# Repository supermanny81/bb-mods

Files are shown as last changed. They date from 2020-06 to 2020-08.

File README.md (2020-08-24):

# A collection of BB8 mods

[][cc-by]

Things I've done to my BB8 along the way.

## Chargeport and Power Switch

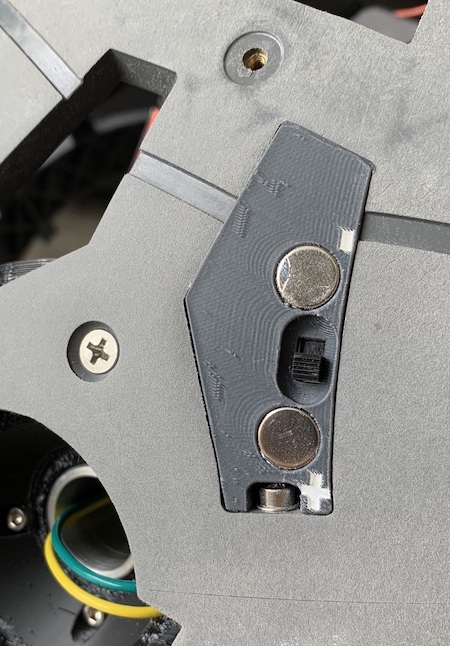
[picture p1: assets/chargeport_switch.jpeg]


The relay I used can be found on Amazon, but I have seen comparable models elsewhere.

https://www.amazon.com/gp/product/B07L6Y7LVW/ref=ppx_yo_dt_b_search_asin_title?ie=UTF8&psc=1

[Charge port power switch](stls/charge_port_micro_switch.stl) - Replaced the wireless relay with a solid state one.

## Dome Lenses

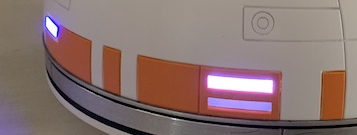
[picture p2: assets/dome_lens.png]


New lenses for addressable LEDs, intended to remove the hot spots.

[Lens for front logics, print 2 of these](stls/dome_front_logics.stl)

[Lens for back logics](stls/dome_back_logics.stl)

## Halo Eletronics Mount

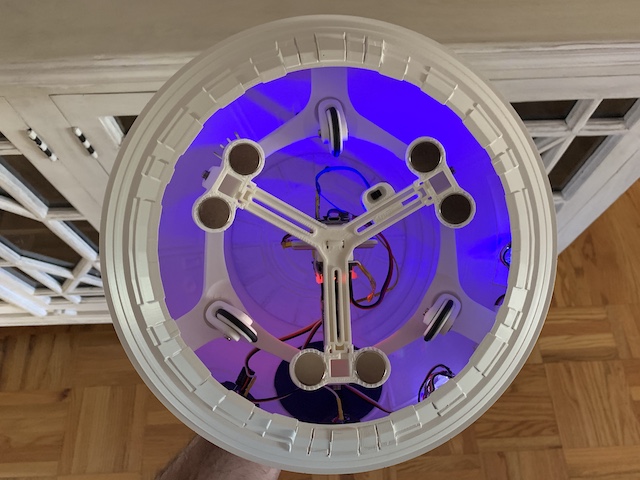
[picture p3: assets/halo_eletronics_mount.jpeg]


Lowers the center of gravity for the battery, provides a mount for the dome's electronics and a switch.  The switch is easily accessible and the dome can be plugged in to charge while on the droid.

[Halo Brace](stls/halo_brace.stl)

[Halo Battery Mount](stls/halo_battery_mount.stl)

[Halo Switch Mount](stls/halo_switch_mount.stl)

## New Lens for Panel 2

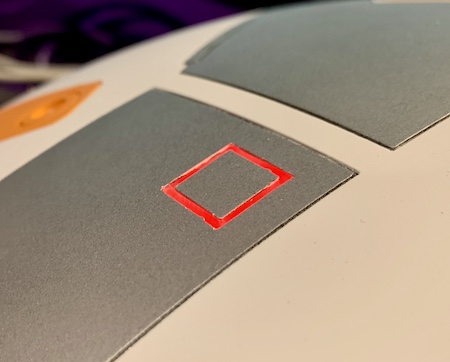
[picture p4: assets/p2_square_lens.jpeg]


[P2 Square Lens STL](stls/p2_square_lens.stl) - A neopixel lens used with Cary's thin panels, this fits in panel 2's square cutout.

## Wireless firmware uploads and control!!!!

One, if not my favorite mods.

[Wireless Firmware Upload and Editing](firmware_upload.md) - With a few simple modifications you can upload new firmware and edit your drive settings no disassembly required.

## WAGO Connector Mount

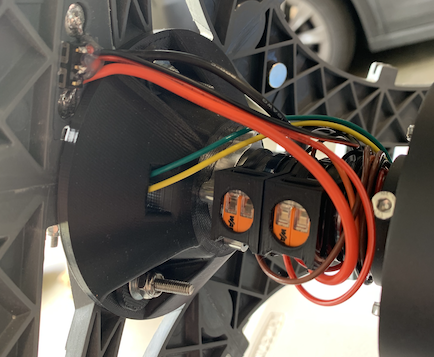
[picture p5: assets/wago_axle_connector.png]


[WAGO Axle Mount STL](stls/wago_axle_mounts.stl) - Easily secure WAGO connectors to your axle using a zip tie.  Can support 4 WAGO connectors per axle.

## Things I've passed up...

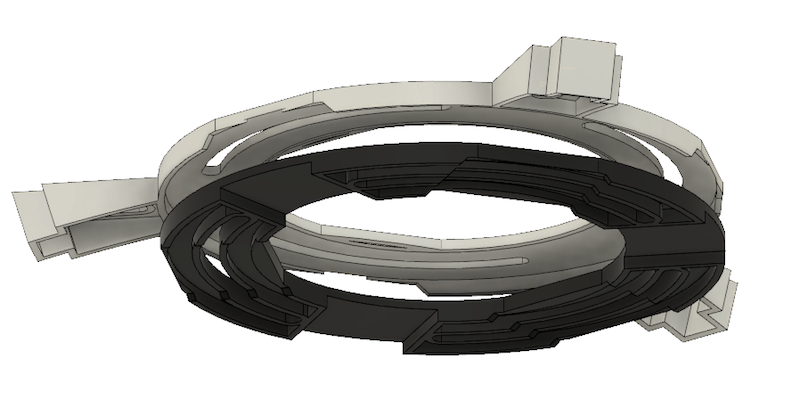
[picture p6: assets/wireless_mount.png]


Mount for induction power coils.  These slide into the Halo setup easily.  I decided to not go this route because of the enefiecient power transfer.  The transmitter coils tolerance for out of spec voltage was bad.  I fried my first.  After regulating it, then looking at the power recived on the other end, it about a 50% power loss.  That coupled with the expensive slip ring and parts, I decided to abandon my effort.  But it's here if you like.

https://www.amazon.com/gp/product/B076H1J7V1/ref=ppx_yo_dt_b_search_asin_title?ie=UTF8&psc=1

[Halo Receiver Mount](stls/halo_receiver_mount.stl) - The receiving mount which attaches the magnet mounts.

[Halo Transmitter Mount](stls/halo_transmitter_mount.stl) - The transmitter mount which attaches the mount inside the body.

[Halo Electronics Mount](stls/halo_electronics_mount.stl) - The board for the dome slides into this mount.

[cc-by]: http://creativecommons.org/licenses/by/4.0/
[cc-by-shield]: https://img.shields.io/badge/License-CC%20BY%204.0-lightgrey.svg

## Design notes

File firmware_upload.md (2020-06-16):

# Wireless flashing and drive editing

There are several settings that are required for wireless firmware flashing to work along with some minor modifications to the hardware.  

The `AT+POLAR` command tells the HC-05 module to use the status LED at it default setting but changes the behavior on the state pin, instead of going high when a serial connection is opened the pin will go low.  Essentially the state pin emulates the DTR pin functionality used with FTDI chips on Arduinos.

Once the software side is configured, you will need a small hardware mod to help emulate the DTR pin/reset switch.

### Software Mods

#### Configuration changes to the modules

Start by changing the settings on your dome's HC-05 module while in `AT Mode`.

```bash
AT+POLAR=1,0
AT+UART=115200,0,0
```

You will need to apply change the baud rate on the HC-05 master used in body to communicate with the dome.

```bash
AT+UART=115200,0,0
```

*I went an extra step further here and made sure that the only address the master module was allowed to bind to was the dome.  You can get the dome HC-05 module's address by running the command `AT+ADDR?` while in `AT` mode.  Then on the master HC-05 run 'AT+BIND=98d3,35,710c09` (but replace 98d3,35,710c09 with your dome's HC-05 module).*

The drive and dome firmware will then need to be updated to use this new baud rate.  The default is current 57600, but the boot loader on new Arduino Nanos expects upgrades at 1152000.

#### Configuring the Drive Console

Now choose a name for console access to your BB unit.  I chose **BB8 Drive Console**.  Remember this name and the pass code you pick, you need to connect this port for changing drive settings and flashing firmware.

**NOTE: Do not use the same passcode that you used for your dome and body HC-05s.**

```
AT+NAME=XXXXXXXX
AT+PSWD=XXXX
AT+ROLE=0
AT+CMODE=1
AT+ROLE=0
AT+POLAR=1,0
AT+UART=115200,0,0
AT+RESET
```

No firmware updates are necessary to enable wireless flashing and drive editing, the drive's Serial0 already runs at the required 115200 bps.

### Hardware Mods

Once configured, make the following circuit.  Technically you can get away with just the 1uf capacitor.  In my case it sometimes failed to reset on when running from arduino's voltage regulator.  Adding the 15k resistor brings the voltage to the reset pin closer to 3v. There is a 10k resistor on the other side of the reset pin, so you are making a voltage divider here . (On my dome, I used an external power supply at 5.2v, without the resistor the voltage never dropped long enough to trigger a reset.)

#### Dome PCB Modifications

Here we are connecting the state pin on the dome's HC-05 module to the reset pin on the dome's PCB with a capacitor in between to *bounce* the voltage drop and trigger a reset on an upload attempt.  Note that the facing the reset pin has a 15k resistor going to ground.

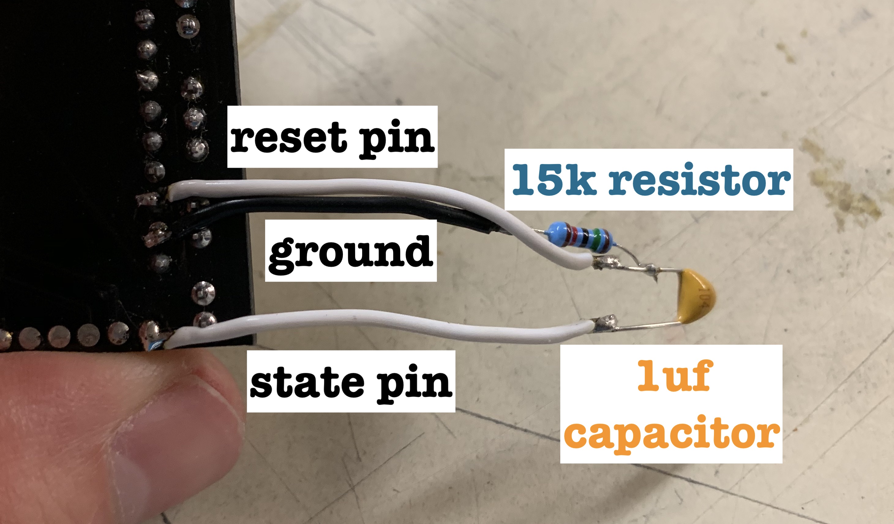
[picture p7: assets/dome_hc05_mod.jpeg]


#### Body (HC-05 Drive Console modifiactions)

I used a ribbon cable created a 5 pin header to connect my drive's HC-05 serial console to the main PCB.  Using a ribbon cable I was able to route my HC-05 module away and secure it to the drive.

Starting from the back side.  Build the same circuit we did for the dome's PCB.  Once again, you will be connecting the HC-05 module's state pin to the reset pin with a 1uf capacitor in between.  Also note again, the resistor goes from a ground pin to leg on the reset side of the capacitor.
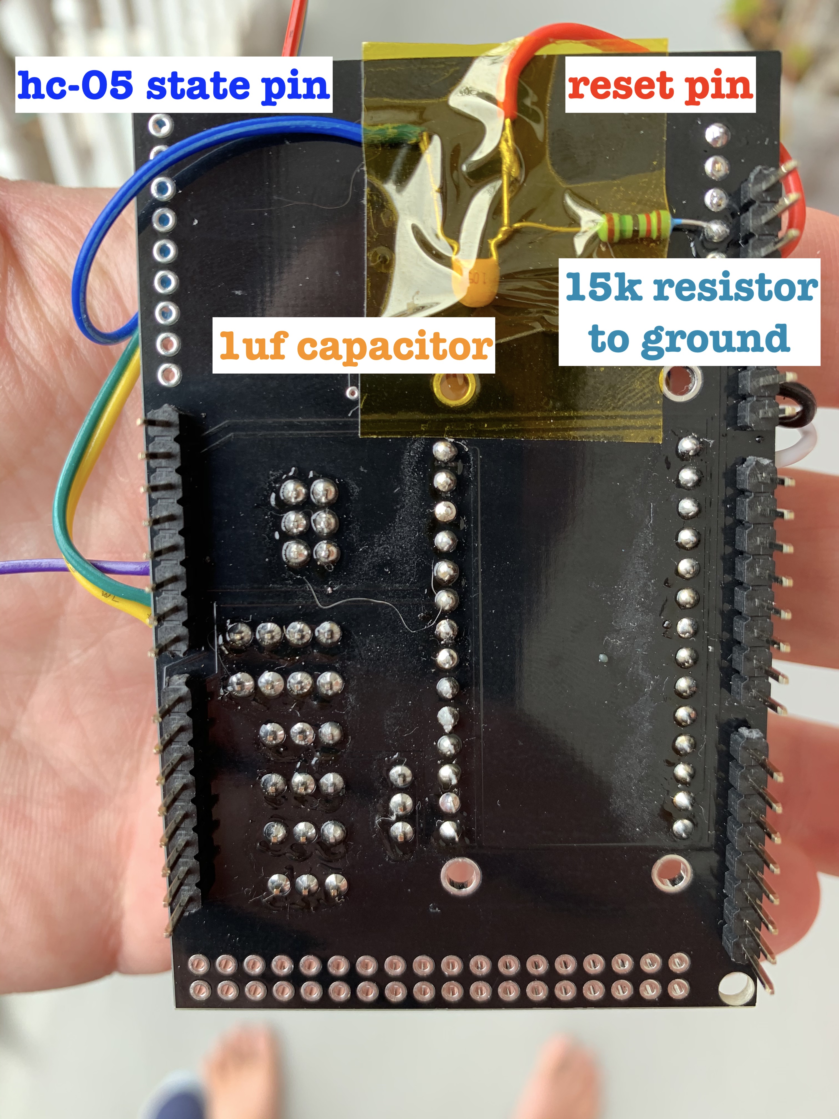
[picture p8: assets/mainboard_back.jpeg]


Once the state pin is connected, flip the board over and make the next 4 connections.  5V, ground, TX, and RX.  You solder them inplace like I did or use a 4 pin header and plug it directly into the board (it's already labled HC-05 along with it's pin outs).  I just got carried away with the soldering iron. :P

*Ignore the voltage divider and body LEDs for now.*

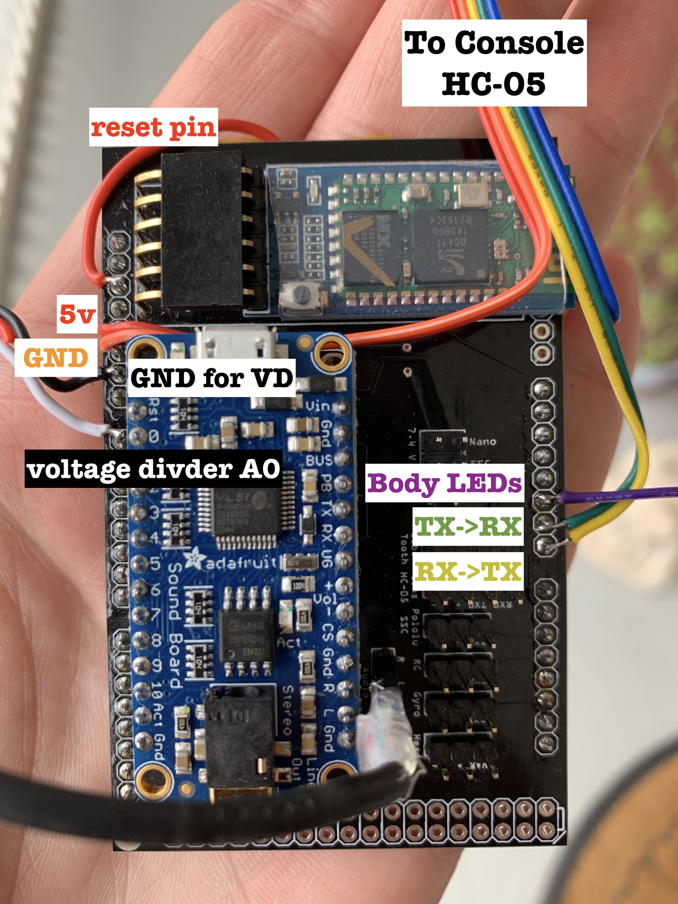
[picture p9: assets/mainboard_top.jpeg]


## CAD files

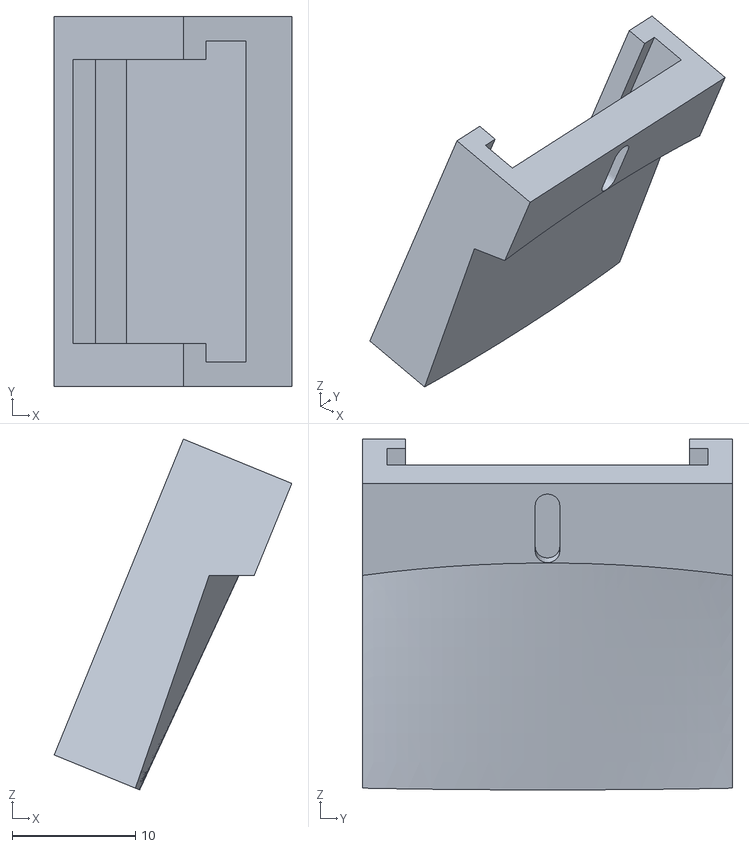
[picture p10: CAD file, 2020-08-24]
stls/halo_electronics_mount.stl
19.3 x 30.0 x 28.4

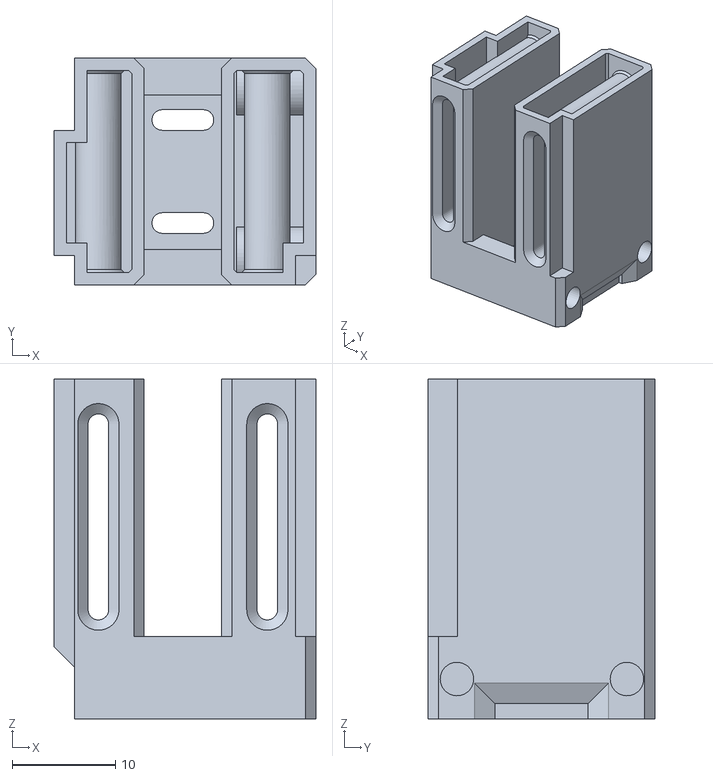
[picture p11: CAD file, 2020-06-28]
stls/halo_battery_mount.stl
25.4 x 22.0 x 33.0

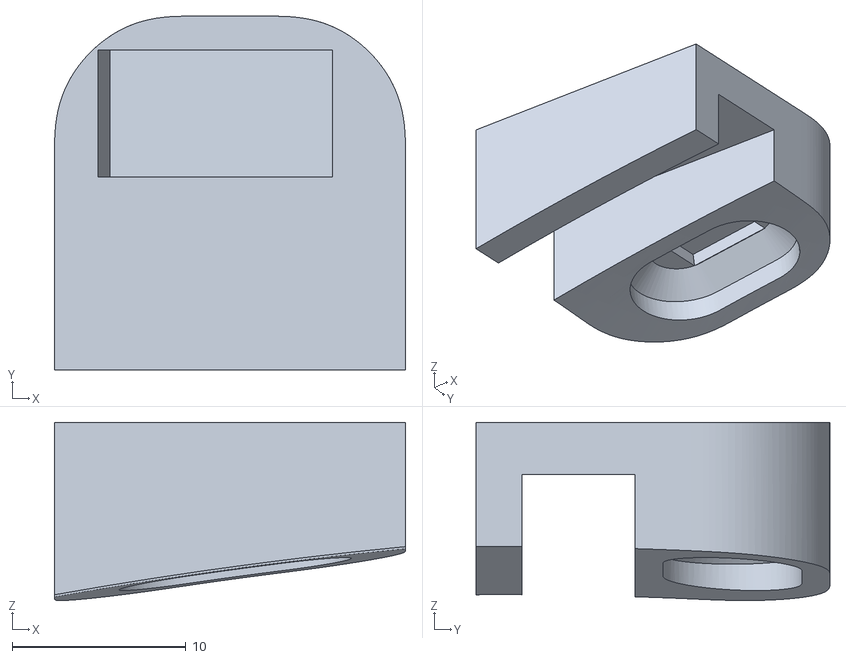
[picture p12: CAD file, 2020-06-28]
stls/halo_switch_mount.stl
20.2 x 20.4 x 10.3

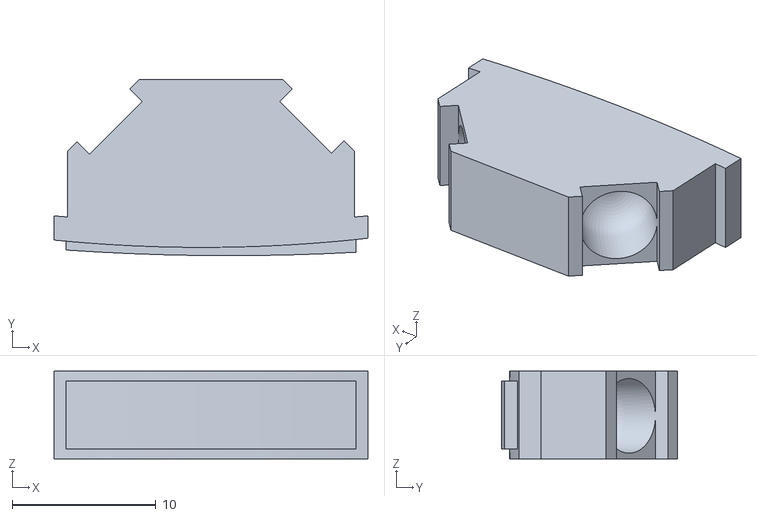
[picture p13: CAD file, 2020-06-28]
stls/dome_back_logics_lens.stl
21.9 x 12.3 x 6.12

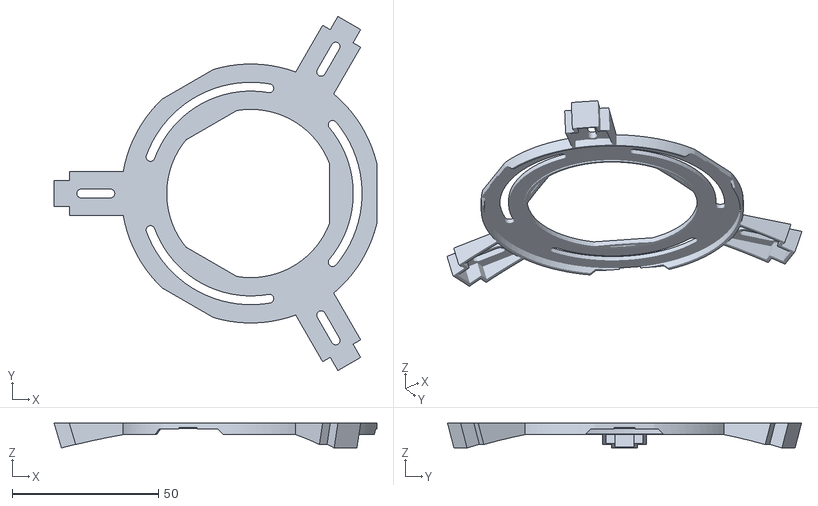
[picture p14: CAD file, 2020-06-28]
stls/halo_receiver_mount.stl
110.4 x 121.0 x 8.50

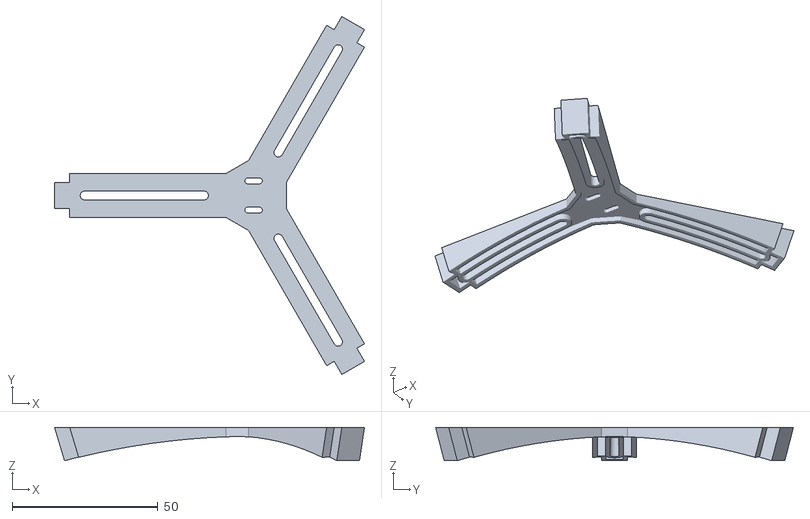
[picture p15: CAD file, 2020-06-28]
stls/halo_brace.stl
106.4 x 122.8 x 11.5

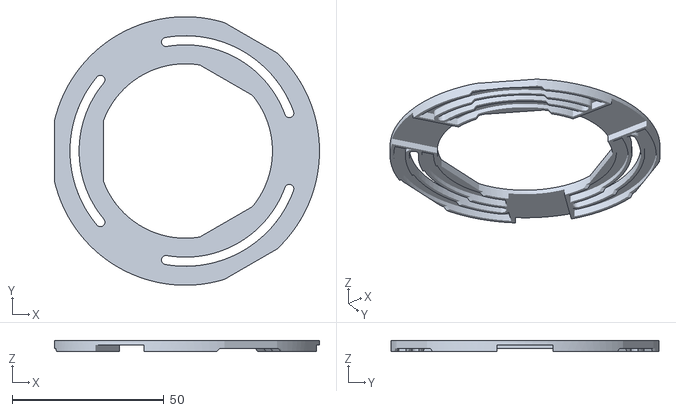
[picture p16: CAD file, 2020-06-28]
stls/halo_transmitter_mount.stl
87.4 x 88.5 x 3.50

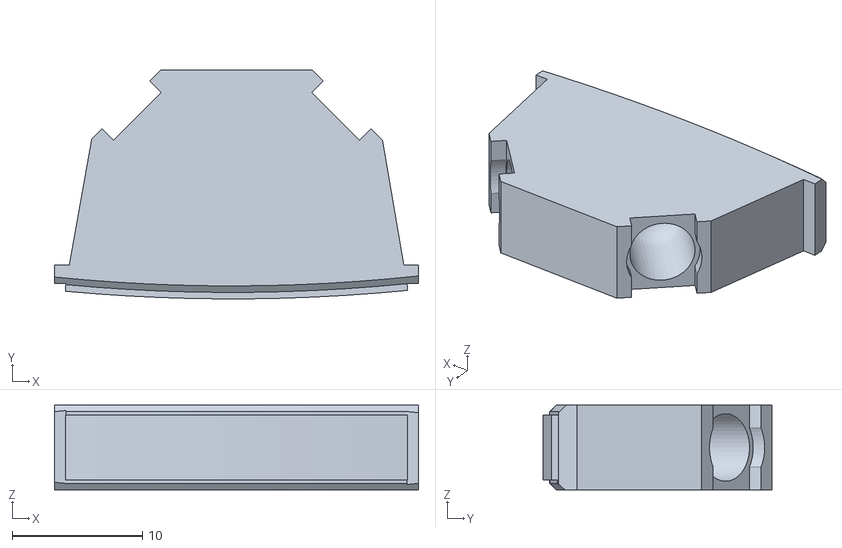
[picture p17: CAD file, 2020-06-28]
stls/dome_front_logics_lens.stl
28.0 x 17.6 x 6.53

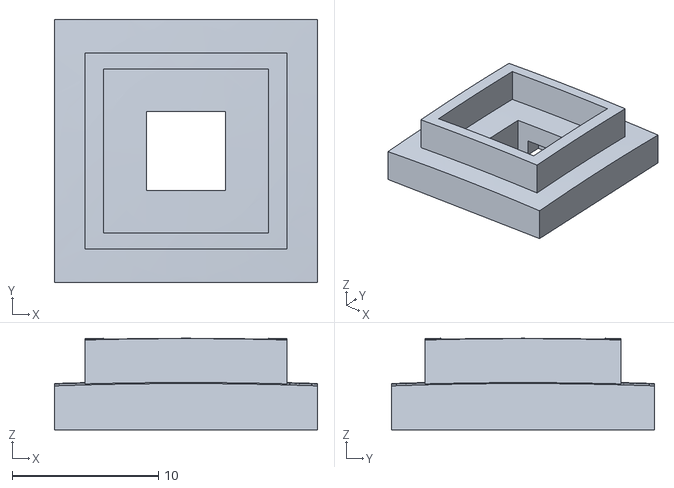
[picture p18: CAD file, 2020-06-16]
stls/p2_square lens.stl
18.0 x 18.0 x 6.27

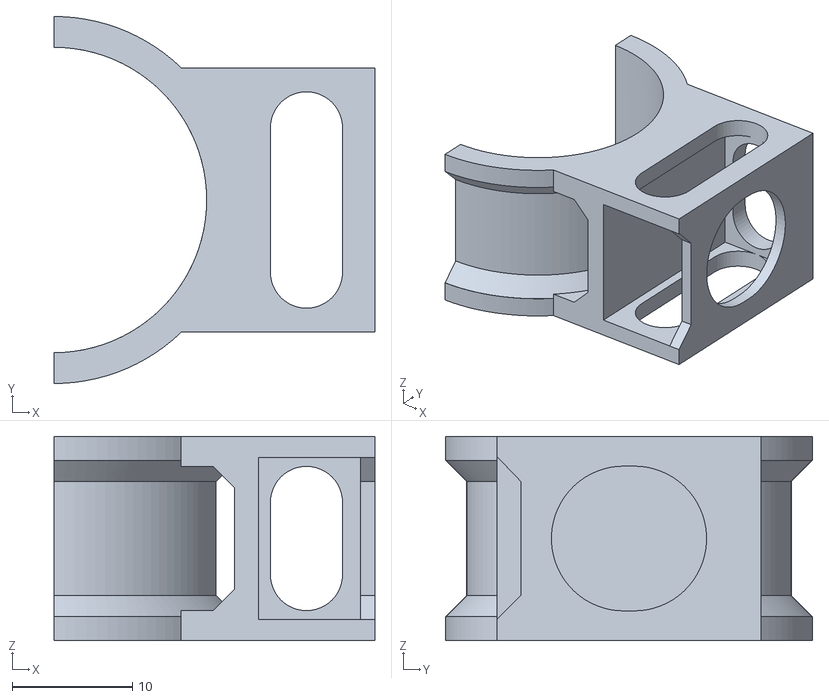
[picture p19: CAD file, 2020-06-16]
stls/wago_axle_mount.stl
26.7 x 30.5 x 17.0

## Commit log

2020-06-16 intial project commit
    [p2_square lens.stl, wago_axle_mount.stl]
2020-06-28 more mods
    [dome_back_logics_lens.stl, dome_front_logics_lens.stl, halo_battery_mount.stl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]
2020-08-24 Added electronics mount
    [halo_electronics_mount.stl]

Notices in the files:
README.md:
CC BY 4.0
